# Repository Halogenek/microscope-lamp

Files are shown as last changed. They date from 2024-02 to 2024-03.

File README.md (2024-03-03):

# Microscope Lamp
Lightning is key in photography. I started to do extreme electronics macrophotography using a 4X microscope objective: [(blog post)](https://niemczuk.tech/2024/02/11/detailed-macrophotography-of-PCBs), but the photographs had low contrast and shadows. So I created this little USB-C powered LED fixture that fits on top of the microscope objective and illuminates the scene.
All files (PCB, 3D housing, BOM) are in the repository files. Feel free to build your own.

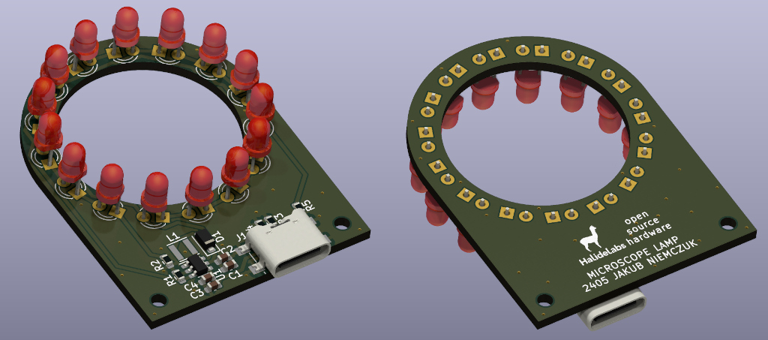
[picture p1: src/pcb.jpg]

</br>
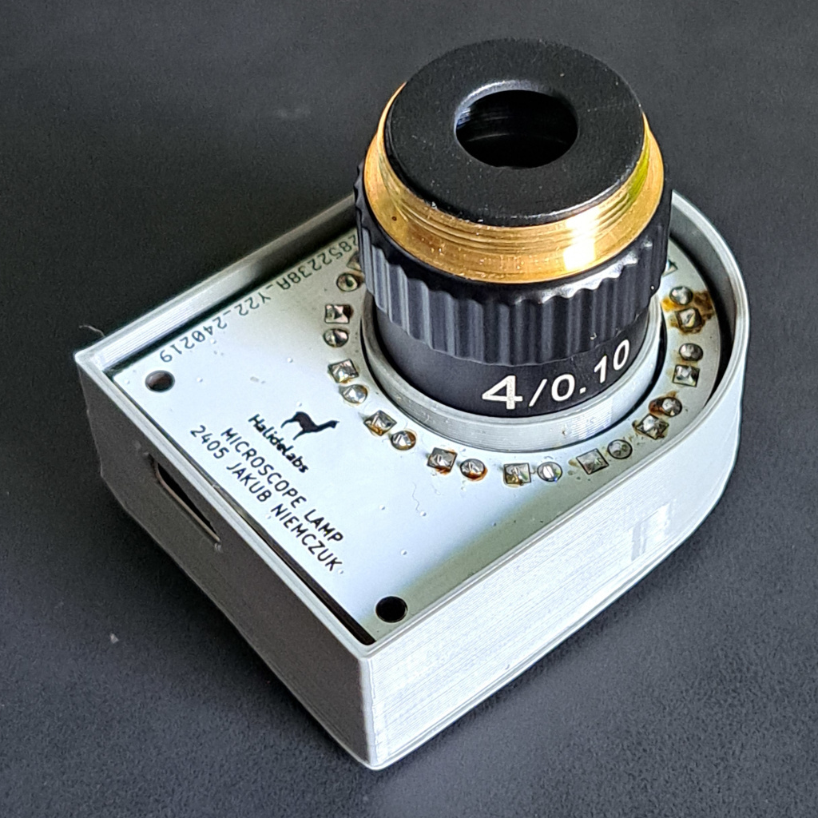
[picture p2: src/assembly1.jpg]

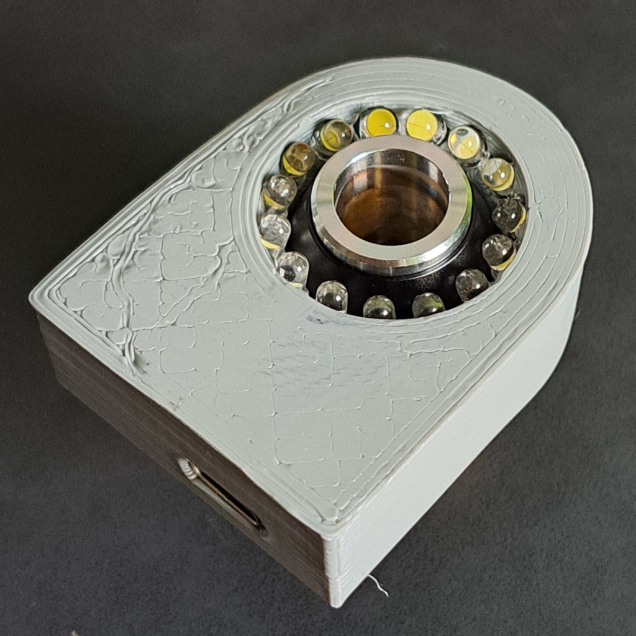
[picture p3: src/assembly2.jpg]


 <p xmlns:cc="http://creativecommons.org/ns#" xmlns:dct="http://purl.org/dc/terms/"><span property="dct:title">Microscope Lamp</span> by <a rel="cc:attributionURL dct:creator" property="cc:attributionName" href="https://niemczuk.tech">Jakub Niemczuk</a> is licensed under <a href="http://creativecommons.org/licenses/by-nc-sa/4.0/?ref=chooser-v1" target="_blank" rel="license noopener noreferrer" style="display:inline-block;">CC BY-NC-SA 4.0</a></p>

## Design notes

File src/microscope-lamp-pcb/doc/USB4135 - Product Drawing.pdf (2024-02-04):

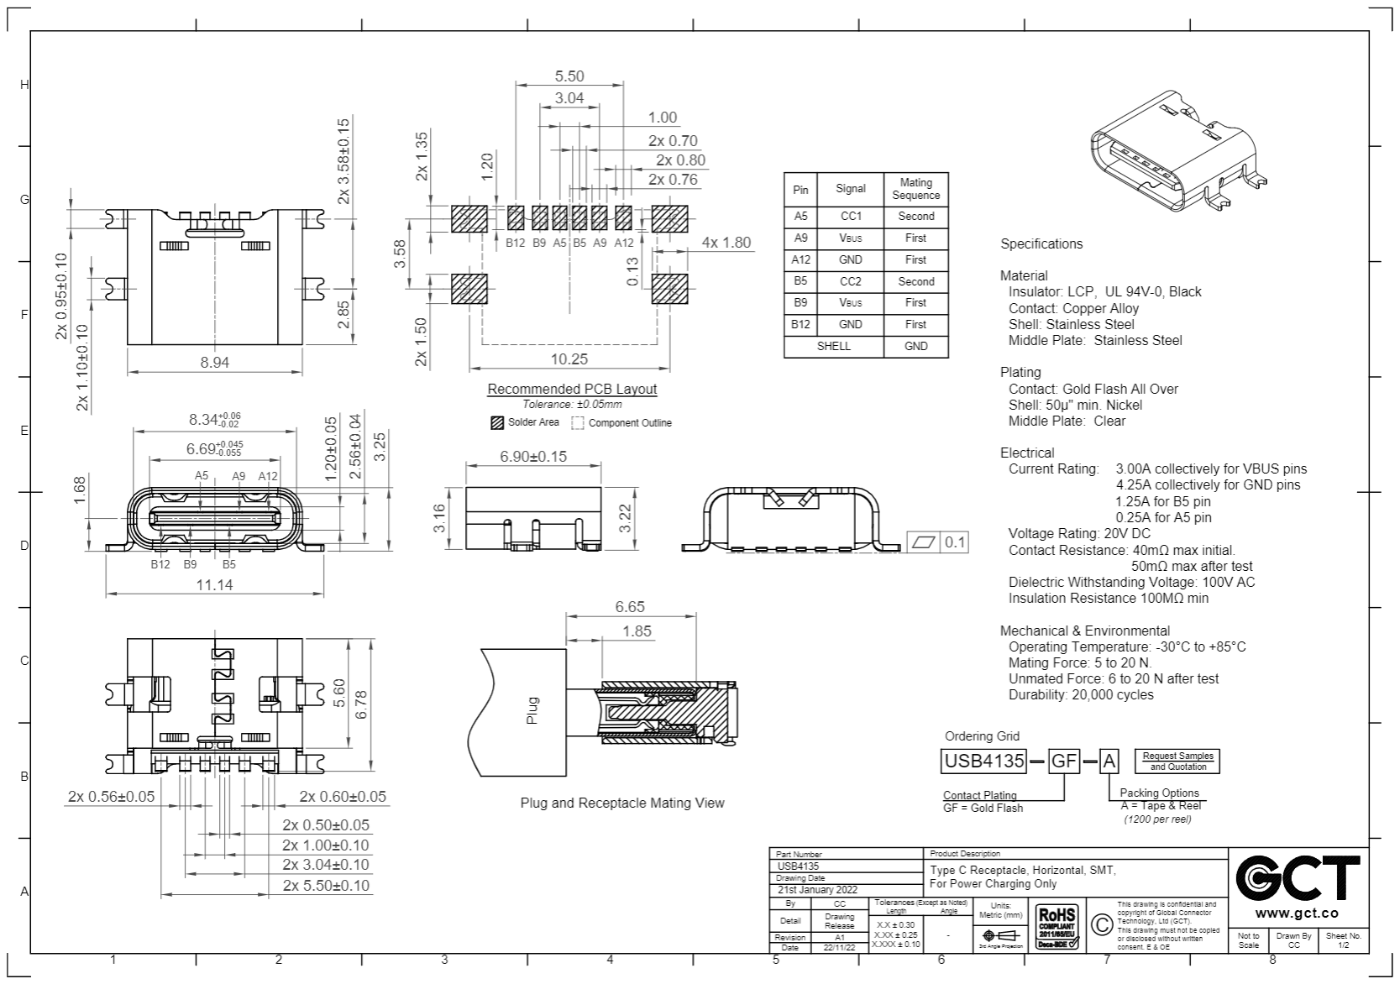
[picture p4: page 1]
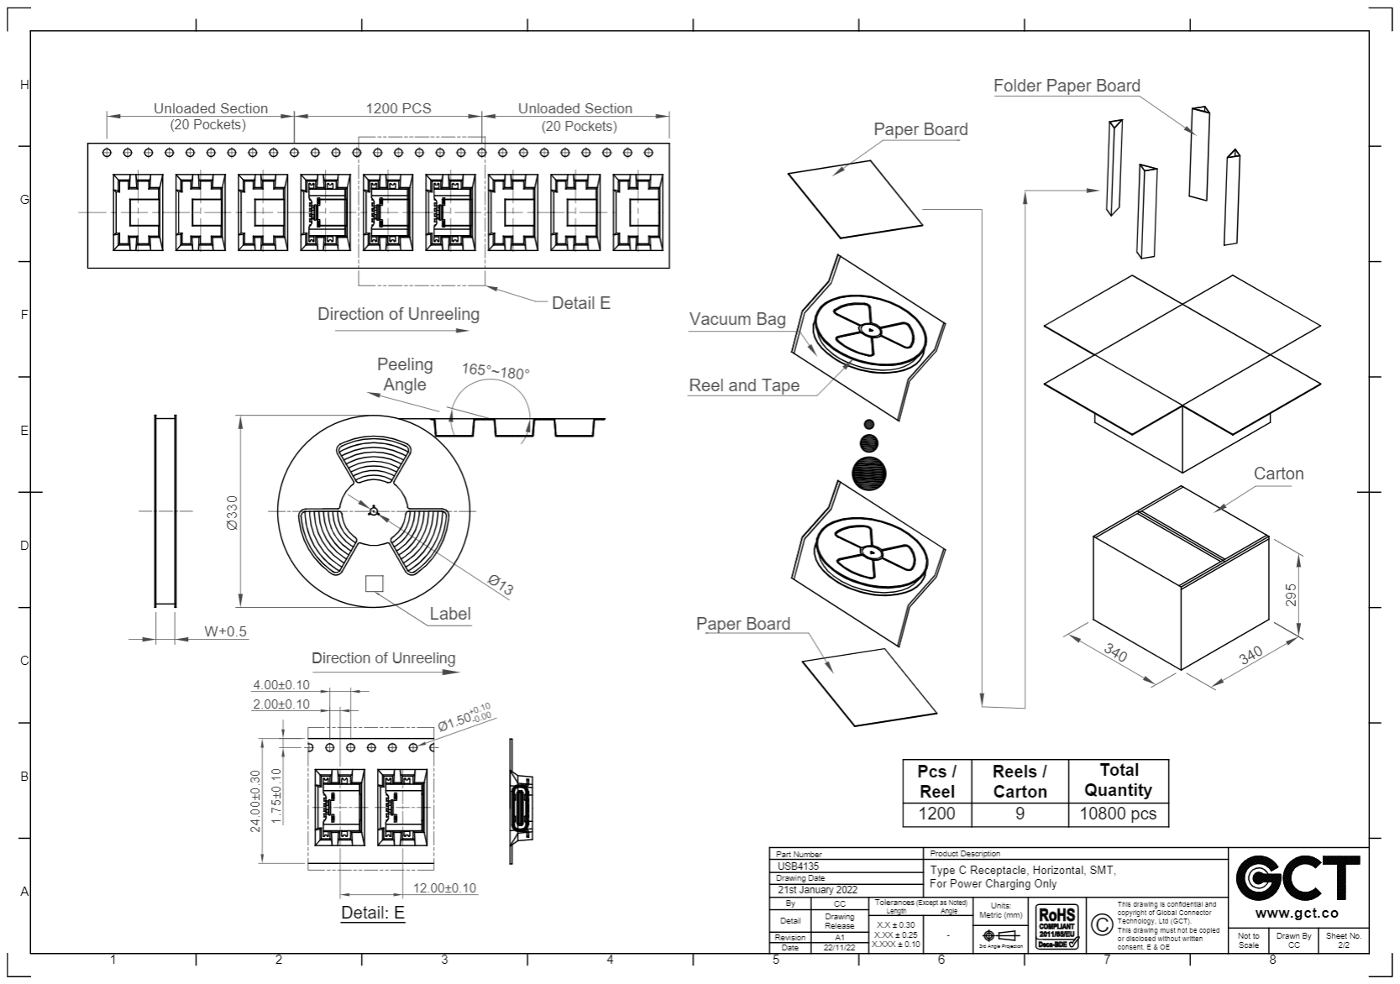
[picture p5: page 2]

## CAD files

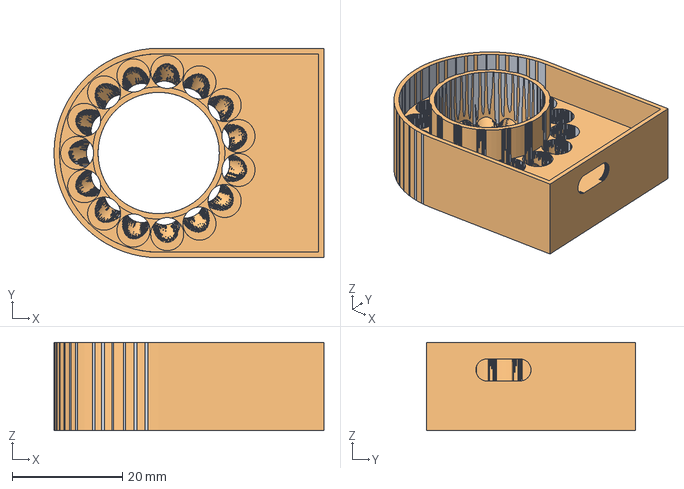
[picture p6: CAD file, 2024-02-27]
src/3d-printed-body/microscope-lamp-body.FCStd
49.0 x 38.0 x 16.0 mm
Pocket005 (Meshed)

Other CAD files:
src/3d-printed-body/microscope-lamp-body.stl

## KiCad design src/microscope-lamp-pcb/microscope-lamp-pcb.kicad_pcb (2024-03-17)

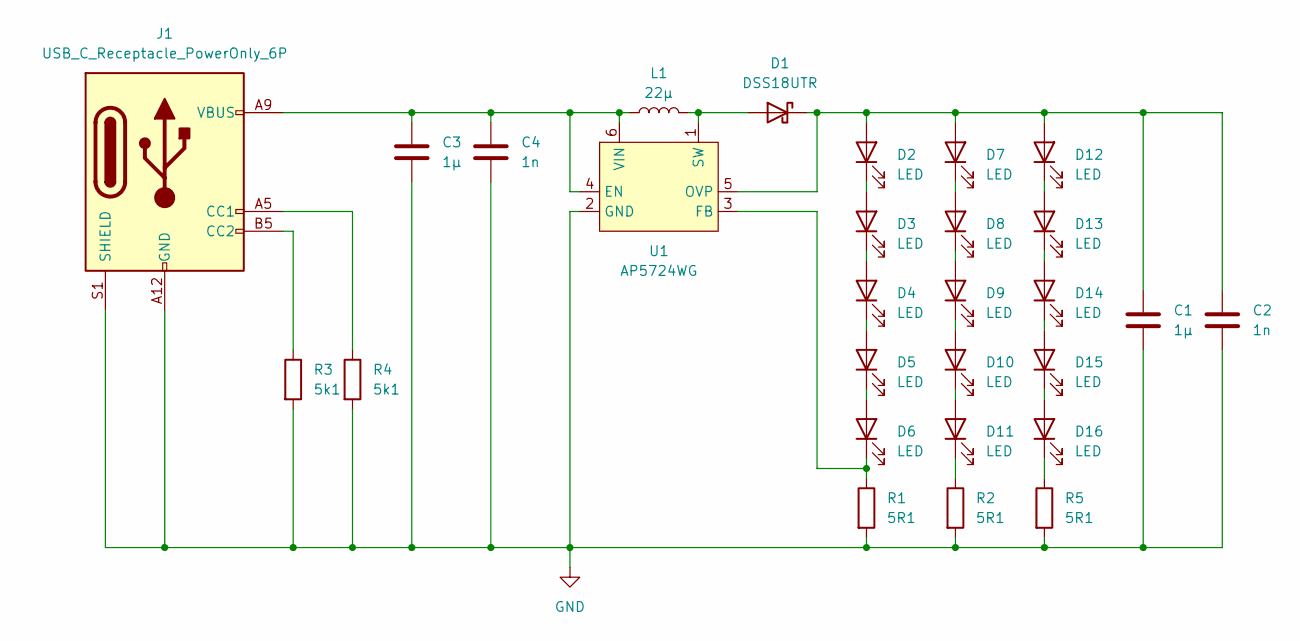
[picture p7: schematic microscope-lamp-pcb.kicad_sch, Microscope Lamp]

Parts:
C1, C3: 1µ; C_0603_1608Metric
C2, C4: 1n; C_0603_1608Metric
D1: DSS18UTR; D_SOD-123F
D2, D3, D4, D5, D6, D7, D8, D9, D10, D11, D12, D13, D14, D15, D16: LED; LED_D3.0mm
J1: USB_C_Receptacle_PowerOnly_6P; USB_C_Receptacle_GCT_USB4135-GF-A_6P_TopMnt_Horizontal
L1: 22µ; L_Taiyo-Yuden_NR-30xx
R1, R2, R5: 5R1; R_0603_1608Metric
R3, R4: 5k1; R_0603_1608Metric
U1: AP5724WG; TSOT-23-6

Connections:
GND: C1.2, C2.2, C3.2, C4.2, J1.A12 (GND), J1.B12 (GND), J1.S1 (SHIELD), R1.2, R2.2, R3.2, R4.2, R5.2, U1.2 (GND)
unnamed: D1.2 (A), L1.2, U1.1 (SW)
unnamed: C1.1, C2.1, D1.1 (K), D2.2 (A), D7.2 (A), D12.2 (A), U1.5 (OVP)
unnamed: D2.1 (K), D3.2 (A)
unnamed: D3.1 (K), D4.2 (A)
unnamed: D4.1 (K), D5.2 (A)
unnamed: D5.1 (K), D6.2 (A)
unnamed: D6.1 (K), R1.1, U1.3 (FB)
unnamed: D7.1 (K), D8.2 (A)
unnamed: D8.1 (K), D9.2 (A)
unnamed: D9.1 (K), D10.2 (A)
unnamed: D10.1 (K), D11.2 (A)
unnamed: D11.1 (K), R2.1
unnamed: D12.1 (K), D13.2 (A)
unnamed: D13.1 (K), D14.2 (A)
unnamed: D14.1 (K), D15.2 (A)
unnamed: D15.1 (K), D16.2 (A)
unnamed: D16.1 (K), R5.1
unnamed: J1.A5 (CC1), R4.1
unnamed: J1.B5 (CC2), R3.1
unnamed: C3.1, C4.1, J1.A9 (VBUS), J1.B9 (VBUS), L1.1, U1.4 (EN), U1.6 (VIN)

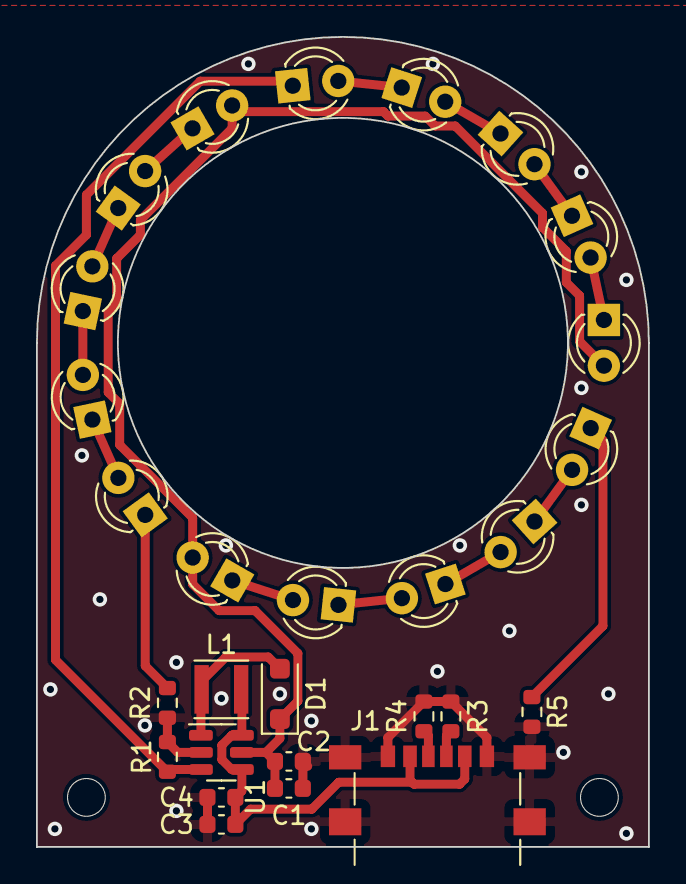
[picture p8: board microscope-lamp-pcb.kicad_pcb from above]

Board: 2 copper layers, 34.0 x 45.0 mm, 30 parts (0 on the bottom side), 21 nets.

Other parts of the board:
H1, H2: MountingHole_2.1mm

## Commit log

2024-02-04 Initial commit.
    Creating schematic and PCB.
    [microscope-lamp-pcb-B_Cu.gbr, microscope-lamp-pcb-B_Mask.gbr, microscope-lamp-pcb-B_Paste.gbr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]
2024-02-04 Adding 3D printed enclosure
    [microscope-lamp-body.FCStd, microscope-lamp-body.stl]
2024-02-18 Updating component info.
    [microscope-lamp-pcb.kicad_sch]
2024-02-27 changing 3D housing
    [microscope-lamp-body.FCStd, microscope-lamp-body.stl]
2024-03-17 removing OSH logo
    [microscope-lamp-pcb-B_Cu.gbr, microscope-lamp-pcb-B_Mask.gbr, microscope-lamp-pcb-B_Paste.gbr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]
